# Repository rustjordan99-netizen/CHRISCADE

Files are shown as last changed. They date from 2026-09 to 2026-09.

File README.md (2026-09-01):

# CHRISCADE

**A custom RP2040 handheld console with a 3D-printed shell, touch-first UI,
Game Boy / Game Boy Color emulation, microSD storage, and a small app library.**

## Quick start

Ready-to-flash firmware is in the clearly marked
[FLASH-ME](FLASH-ME/) folder. Open it and use
[`CHRISCADE_v273_FLASH_THIS.uf2`](FLASH-ME/CHRISCADE_v273_FLASH_THIS.uf2).
The [3MF-FILES](3MF-FILES/) folder contains the printable enclosure parts.
The author-supplied optimized Crystal test build is documented in
[OPTIMIZED-CRYSTAL](OPTIMIZED-CRYSTAL/).

<p align="center">
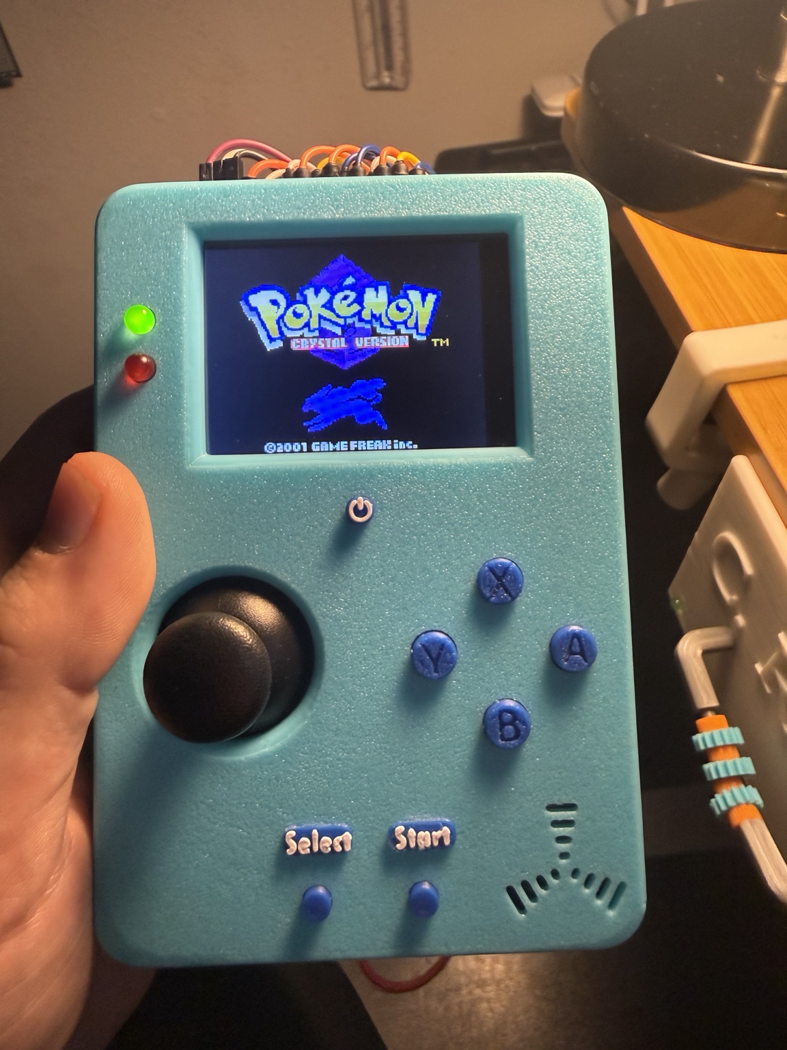
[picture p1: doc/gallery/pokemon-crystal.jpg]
CHRISCADE running Pokémon Crystal
  
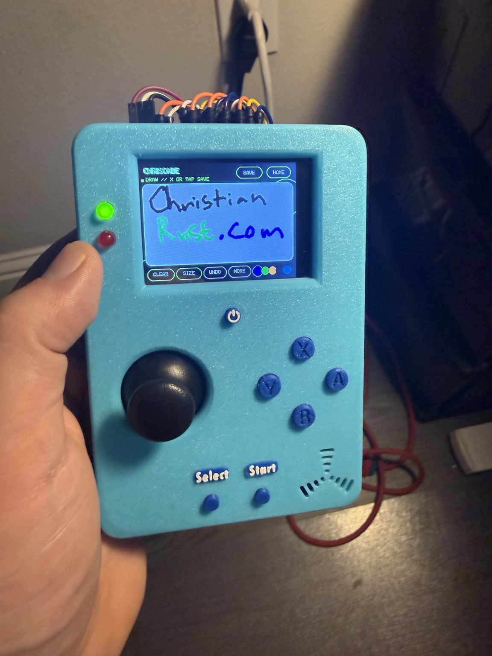
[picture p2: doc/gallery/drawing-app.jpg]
CHRISCADE drawing app
  
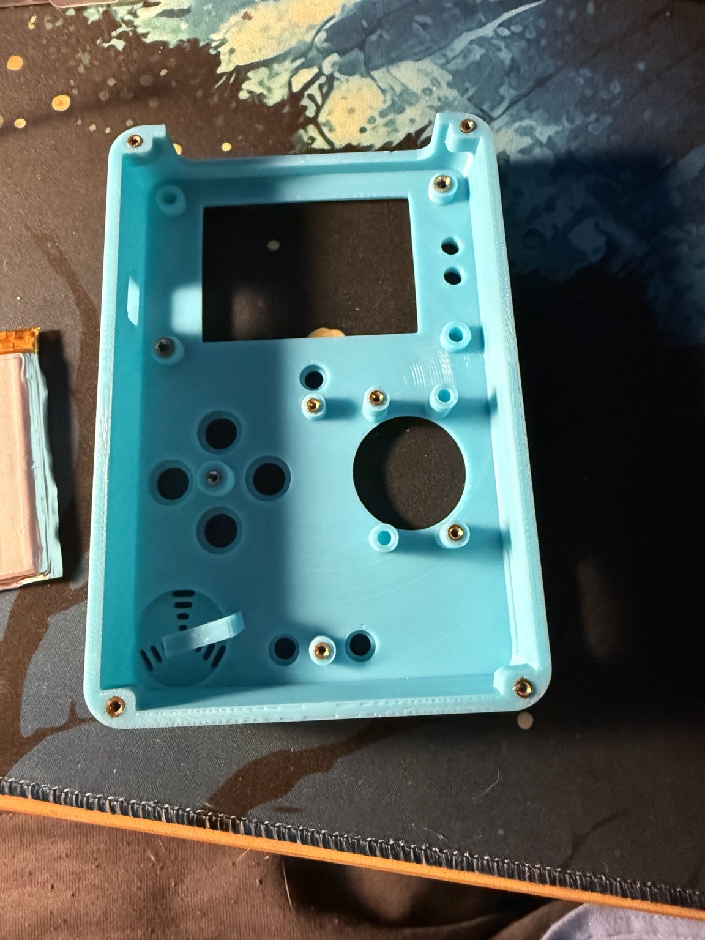
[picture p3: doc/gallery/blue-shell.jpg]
CHRISCADE printed shell interior
  
</p>

<p align="center"><i>From enclosure concept to printed handheld and custom firmware.</i></p>

<p align="center">
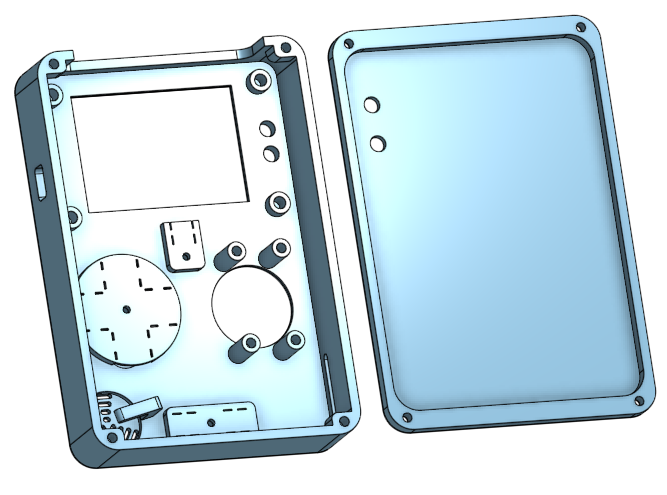
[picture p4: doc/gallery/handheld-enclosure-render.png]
CHRISCADE enclosure CAD render
  
</p>

## What it does

- Runs legally owned Game Boy and Game Boy Color games from a FAT32 microSD card
- Saves game progress to the SD card
- Includes an author-supplied optimized Pokémon Crystal test-build workflow for this RP2040 handheld
- Provides a themed game launcher with touch and physical controls
- Includes Draw, Calculator, Timer / Stopwatch / Alarm, Metronome, Settings, and Gallery apps
- Captures screenshots into per-game and per-app SD folders; screenshots can be renamed or edited
- Supports a custom animated boot sequence, boot themes/sounds, brightness, LEDs, battery status, audio, and sleep controls
- Uses a USB game-transfer workflow so games can be managed without removing the SD card

## Hardware

- CrowPanel RP2040 touchscreen controller/display
- Parallax joystick
- 6 mm A/B/X/Y buttons and approximately 3.3 mm Start, Select, and Power buttons
- 10 kΩ volume potentiometer, speaker/amplifier, status LEDs, microSD, and jumper wiring
- Custom 3D-printed enclosure and controls

The printable shell and button files, component list, and assembly notes are in
[hardware/README.md](hardware/README.md).
The printable files are also directly accessible in the root
[3MF-FILES](3MF-FILES/) folder.

## CHRISCADE pinout

This is the active CrowPanel RP2040 configuration in `platformio.ini` and
`src/common.h`:

| Function | Pico GPIO / mapping |
| --- | --- |
| A / B buttons | GP0 / GP1 |
| X / Y buttons | GP2 / GP3 |
| Start / Select | GP4 / GP5 |
| Low-power button | GP20 |
| Joystick X / Y | GP26 / GP27 (analog) |
| Speaker audio | GP19 (PWM) |
| Volume potentiometer | GP28 (analog) |
| TFT SCLK / MOSI / MISO | GP10 / GP11 / GP12 |
| TFT CS / DC / RST / backlight | GP9 / GP8 / GP15 / GP18 |
| Touch controller CS | GP16 |
| microSD CS | GP22 |

The TFT, touch controller, and microSD share the SPI1 bus on GP10–GP12 and
use separate chip-select lines. The six directional controls are handled by
the CrowPanel input mapping in firmware; the joystick supplies the analog
direction input. Verify the board revision and wiring before connecting power.

## Build

Install PlatformIO, then build the `pico` environment:

```sh
pio run -e pico
```

The UF2 is created at `.pio/build/pico/firmware.uf2`. Hold BOOTSEL while
connecting the Pico, then copy that file to the mounted `RPI-RP2` drive.

## Limitations

- Game Boy / Game Boy Color compatibility is experimental; some games may
  freeze, fail to launch, or run below full speed.
- The optimized Pokémon Crystal build is a hardware-specific test build, not a
  general replacement for every Crystal ROM or emulator.
- Larger or more demanding GBC games can still stutter, especially during
  overworld streaming, audio-heavy scenes, or menu transitions.
- The RP2040 is overclocked for emulation performance. This can increase heat,
  power use, and long-term hardware stress.
- The current build reserves part of the Pico's flash for the firmware and
  filesystem, so usable ROM capacity is lower than the board's advertised
  flash size.
- SPI display bandwidth and shared peripherals can limit frame rate and may
  produce occasional tearing or input/audio artifacts.
- The enclosure and wiring are custom hardware; fit, button feel, battery
  behavior, and pin compatibility depend on the individual build.
- Only use game files you legally own. ROMs, saves, screenshots, and generated
  firmware binaries are not included in the source repository.

> This repository includes firmware, CAD, and documentation only. It does not
> contain commercial ROMs, save data, screenshots, or generated UF2 releases.
> The optimized Crystal build was provided by Chris Rust for testing, but the
> game file itself is not redistributed here. Use only game dumps you legally own.

## Credits

CHRISCADE is a heavily customized fork built on
[YouMakeTech's Pico-GB](https://github.com/YouMakeTech/Pico-GB), itself based
on deltabeard's Peanut-GB / RP2040-GB work. Thanks to those projects and their
contributors, as well as Bodmer's TFT_eSPI and the other libraries included in
this source tree. Their license notices remain with their respective code.

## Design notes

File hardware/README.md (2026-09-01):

# CHRISCADE hardware

## Core components

| Part | Used in this build |
| --- | --- |
| Main controller/display | CrowPanel RP2040 with integrated touch display |
| Analog control | Parallax joystick |
| Main buttons | 6 mm diameter buttons for A, B, X, and Y |
| Small buttons | Approximately 3.3 mm buttons for Start, Select, and Power |
| Volume | 10 kΩ potentiometer and printed volume spinner |
| Wiring | Jumper wires; quantity and lengths depend on enclosure routing |
| Enclosure | Custom 3D-printed shell and control parts |

The firmware pin assignments and electrical behavior are defined in the source
configuration. Check them before changing any component or wiring.

## Printable files

All printable parts are in the easy-to-find root-level [`3MF-FILES/`](../3MF-FILES/)
folder:

| File | Part |
| --- | --- |
| `front shell.3mf` | Front half of the handheld shell |
| `back.3mf` | Rear half of the handheld shell |
| `button panel.3mf` | Button-panel insert |
| `ABXY.3mf` | A/B/X/Y button set |
| `small buttons.3mf` | Small auxiliary button set |
| `select.3mf` | Select button |
| `start stop.3mf` | Start/Stop button |
| `power.3mf` | Power button |
| `volume spinner.3mf` | Knob for the 10 kΩ volume potentiometer |

## Assembly notes

- Test the display, controls, SD card, speaker, and power wiring before closing
  the case.
- Keep jumper wiring clear of the joystick and button travel.
- Test-fit buttons and the volume knob after printing; printer tolerances vary.
- The CAD files are supplied as `.3mf`, which can be opened directly in most
  modern slicers.

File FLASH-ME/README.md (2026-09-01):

# Flash CHRISCADE

## Use this file

Copy [`CHRISCADE_v273_FLASH_THIS.uf2`](CHRISCADE_v273_FLASH_THIS.uf2) to the
CrowPanel RP2040:

1. Disconnect USB power from the handheld.
2. Hold the board's **BOOTSEL** button while connecting the USB cable.
3. Release BOOTSEL when the `RPI-RP2` drive appears.
4. Copy `CHRISCADE_v273_FLASH_THIS.uf2` onto the `RPI-RP2` drive.
5. Wait for the drive to disappear and the handheld to reboot.

This is the tested v273 build. It includes the gallery folder cleanup, exact
Game Library folder logos, no-flash Undo repaint, and multi-stroke Undo.

Flashing firmware does not erase game saves stored on the microSD card. Keep
the card inserted during normal use, but do not confuse the `RPI-RP2` drive
with the game microSD card.

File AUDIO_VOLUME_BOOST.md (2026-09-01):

# Shared gameplay volume boost — 2026-08-30

New firmware: `CROWPANEL_PICO_GB_ALL_GAMES_LOUDER_AUDIO.uf2`

SHA256: `66492CBF863AC2E16DC949E77C91C271DD29683BA592F66CAFC0C889C4D8CEA5`

Built on the fine-tuned audio firmware. The boost is in the common
`crowpanel_audio_submit` output path, so every GB/GBC game, including GBZ files,
uses it. There are no title checks or per-ROM patches. Doom firmware and the
startup/UI sounds are not changed.

The startup jingle can use full-amplitude square-wave tones. Gameplay audio
mixes several channels, averages stereo to mono, filters the result, and limits
peaks; these have different average loudness. Both already use the same 700/4000
volume-knob thresholds and cubic taper.

The new `audio_output_curve.h` adds 1.5x gain before the existing soft limiter,
precomputed into the existing 321-byte table. Quiet/moderate signals are boosted
more than already-loud peaks. This is not a guarantee of 50% greater perceived
loudness or an exact jingle loudness match. The soft limiter reduces hard
clipping but cannot guarantee distortion-free physical speaker output.

No per-sample arithmetic or table RAM is added. Sample rate, 266 MHz clock,
filter, volume/mute controls, audio queue/IRQ refinements, rendering, saves,
settings and sleep behavior are retained.

Verification:

- Production curve compiled for Cortex-M0+ and executed under Unicorn: all
  321 entries passed silence, monotonicity, non-attenuation, soft-knee continuity,
  signed PWM symmetry and range tests. All larger uint16 inputs clamp safely.
- Queue startup/refill/recovery/reset and 50,000 randomized interleavings passed.
- Release Pico build passed: RAM 257,804 / 262,144 (unchanged), flash
  324,928 / 782,336. Existing unrelated build warnings remain.
- UF2 block numbering, magic and RP2040 family checked: 1,319 blocks, highest
  payload end 0x10052700, below ROM storage at 0x100BF000.
- Previous fine-tune, click-fix, DMA-queue and stable UF2 hashes rechecked;
  none overwritten. No ROM/save/settings files changed. Not auto-flashed.

Hardware test: begin below maximum volume, compare the same scenes with the
previous fine-tune build at the same knob position, and listen for harshness in
busy music/effects. Test more than one game, full mute/resume, and map scrolling.
Actual loudness and speaker distortion still require this listening test.

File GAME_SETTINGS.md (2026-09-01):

# Game-library file settings — 2026-08-30

Firmware: `CROWPANEL_PICO_GB_GAME_SETTINGS.uf2`

SHA256: `3B1583F108E37D3654220772001CB49984AE92162B9525EAADD059A8E6AF7128`

Built on the all-games louder-audio firmware; retains that boost, the guarded
audio queue, sound-generation optimizations and existing game/display settings.

## Controls

- Highlight a game in Game Library and press SELECT, or tap the bottom-right
  SELECT SETTINGS button. B still returns Home; A still loads a game.
- Settings offers Rename and Delete for that highlighted SD file. Touch works,
  as do Up/Down and A. B/SELECT, or tapping the settings footer, returns.
- Rename uses a touch keyboard with uppercase/lowercase, digits, punctuation,
  Space, Delete-character, Clear, Save and Back. The stick and A also operate
  the keyboard; START saves and B cancels. The original extension is kept.
- Delete opens a separate confirmation showing the complete filename, with
  Cancel selected by default. Choose Right then A, or tap Delete, to confirm.
  B/SELECT cancels. Entry input must be released before a new action is read,
  so holding the opening A press/touch cannot also confirm deletion.
- After rename, the A-Z list follows the renamed file to its new position.
  After deletion, selection is clamped and an empty final page returns to the
  previous page. An entirely empty library still supports Back and Settings.

## File protection and limitations

- Only the exact selected `.gb`, `.gbc` or `.gbz` root-directory file is targeted.
  No recursion, paths, wildcard deletion or filesystem formatting.
- The filename policy rejects path separators, control/invalid FAT characters,
  empty/oversized names and Windows device names. Rename preserves extension.
- Existing destination files/directories are never overwritten. SdFat's own
  exclusive-create rename behavior also enforces this. Case-only renames are
  reported as unchanged because the SD filesystem is case-insensitive.
- Read-only files and directories are not modified. Missing files and I/O
  failures are reported rather than treated as successful operations.
- Save filenames are derived from the internal ROM header, not the SD filename.
  These menus never rename or delete save/settings files.
- Deletion removes the SD ROM file. There is no on-device trash/undo; restore
  it by copying the original ROM back. The last flashed ROM on the Pico is not
  erased, so START Last Game can still run that cached copy.
- Avoid removing power/card during any SD update. As with existing save writes,
  filesystem/power failures cannot be made fully transactional here.

## Implementation and verification

- UI uses the current theme helpers, rounded controls and existing click sound.
  Focus and keyboard edits redraw only their changed controls/field.
- The rename editor reuses 512 bytes of the existing flash-sector workspace
  while in menus; it allocates no new persistent buffer or gameplay work.
- `src/rom_file_actions.h` contains the shared filename rules and exact file
  operation. `tests/run_rom_file_actions_test.py` compiles this production code
  for Cortex-M0+ and executes it with an in-memory fake filesystem under Unicorn.
- Tests passed for bounded names, extension retention, UTF-8 filenames,
  traversal/invalid names, case-insensitive collisions, directories, read-only
  attributes, absent files, simulated I/O failures, single-file rename/delete
  and preservation of other game/save/settings entries. No real game file was
  opened, renamed or deleted by these tests.
- Confirm/cancel input release handling, keyboard bounds and page refresh paths
  were source-reviewed. Physical touchscreen behavior still needs a board test.
- Final release build passed. Static RAM **257,804 / 262,144 bytes** (unchanged);
  flash **341,448 / 782,336 bytes**. Menu buffers stay off the small core-0 stack.
- UF2 checked: **1,384 RP2040 blocks**, payload ends **0x10056800**, before ROM
  storage at **0x100BF000**. ROM capacity is unchanged.
- All five prior stable/audio firmware hashes were checked and remain intact.
  New UF2 is separate and has not been flashed automatically.

On-device check: cancel a delete first (A on default Cancel, B, and touch), then
try renaming a test ROM, a duplicate-name rejection, and deleting a backed-up
test ROM. Check the last entry on a page, the empty library, and loading its
existing save after a rename. No actual SD-card files were changed during this
development task.

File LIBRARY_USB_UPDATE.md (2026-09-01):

# CHRISCADE library update — 2026-08-30

Firmware: `CROWPANEL_PICO_GB_LIBRARY_USB_UPDATE.uf2`

SHA256: `E043BF24B14F014035DF7B46D6E470A0CF10B83B0BD06601FF5B4DA20D14B3DC`

## Library and editing

- Removed left/right page controls. Up/Down continuously scrolls through the
  alphabetical library, revealing one game at a time at the visible edge.
  Selection stops at the beginning/end rather than wrapping. Only eight names
  are held in memory; scrolling doesn't allocate the whole library.
- After the final game, Down highlights ADD GAME; Up returns to the last game.
  ADD GAME is also always available by touching its bottom-left button, including
  in an empty library. A opens the highlighted game or Add Game. B returns Home.
- Bottom-right button reads `SELECT // SETTINGS`. It and the physical Select
  button open Rename/Delete for the highlighted game. Existing delete-confirmation
  and save-preservation behavior remains intact.
- Rename has a visible insertion cursor. Tap the name to place it, use the
  on-screen arrows, or press X/Y to move left/right. Typing inserts at that point;
  DEL removes the previous character, not the entire suffix. The view follows
  the cursor for long names, and the original extension is kept.
- The small game-list and larger cartridge-writing Pokeballs share a circular
  pixel mask. Red fill and white fill cannot extend beyond the black outline.

## Add a game without removing the SD card

1. Flash this UF2 as usual, then open Game Library > ADD GAME.
2. Connect the handheld to the PC using a USB data cable.
3. Double-click `SEND_GAME_USB.cmd` in this project folder.
4. Choose a `.gb`, `.gbc`, or `.gbz` file. Select the handheld's COM port from
   the list (not an unrelated serial device).
5. Wait for the verified-success message, then press B on the handheld. The
   refreshed library includes the new file in alphabetical order.

This uses USB serial, **not a drive in File Explorer**. The Windows launcher
uses the existing Python runtime and project-local pyserial, without installing
anything new. Advanced usage: `send_game_usb.py --port COM5 "path/to/Game.gb"`.
Close any serial monitor holding the same COM port before running it.

The uploader accepts only new ROM files at the SD root. It cannot read files
back, expose raw sectors, overwrite existing names, format the card, or delete
other files. Saves/settings are not upload targets. Pick a different filename
if a game already exists. The 16 MiB transfer cap is not a new emulator/flash
capacity: existing ROM-size and supported-format limits still apply when loading.

Uploads use bounded 512-byte acknowledged chunks and a streaming CRC32 check.
The ROM appears in the library only after successful verification and rename
from an exclusively created temporary file. B cancels; a stalled transfer times
out after ten seconds without a byte. Cancellation/error attempts to remove only
that session's new temporary file. Existing temporary files are never reused or
removed. Sudden power loss or card failure can leave an incomplete `CC*.TMP`
file; it is not shown as a game. As with all SD writes, avoid unplugging power or
removing the card during the transfer—filesystem corruption cannot be ruled out.
Deep-sleep polling pauses during an active transfer and resumes afterward.

## Implementation and checks

- USB reception and SD writes run in the menu foreground, before the second
  display core and emulator audio start. No USB callback touches the shared SPI
  bus. Raw USB mass storage remains disabled.
- Reuses the existing flash-sector workspace for upload data, rename text and
  directory-scan scratch at nonoverlapping offsets. No new persistent buffer or
  per-frame gameplay work. Nested filename buffers were moved off core 0's 2 KB
  stack. Only changed rows/controls repaint while scrolling, not the full screen.
- Release build passes: static RAM **257,804 / 262,144 bytes**, unchanged;
  flash **352,696 / 782,336 bytes**.
- UF2 verified: **1,428 RP2040 blocks**, payload end **0x10059400**, safely below
  the ROM area at **0x100BF000**. All six previous stable/recent firmware hashes
  remain unchanged. No board was flashed automatically.
- `tests/run_library_update_tests.py`: actual Cortex-M0+ helper code, fake SD.
  Covers cursor insertion/deletion/UTF-8/bounds, both Pokeball masks, continuous
  scrolling for libraries of 0–30 games, short shifted windows after deletion,
  upload header/CRC validation, exclusive creation, existing-name collisions,
  write/sync/rename failures, cancellation, and preservation of original files.
  Includes the earlier rename/delete policy regression tests.
- `tests/test_usb_rom_sender.py`: five tests, mock serial/in-memory files only;
  exact payloads across chunk boundaries, Unicode filenames, duplicates,
  incomplete writes, rejected extensions and empty inputs.
- Audio regressions pass: 50,000 queue interleavings; 4,096 sample/state-exact APU
  frames against the stored reference; all 321 output-table entries and bounds.
  Existing all-games loudness boost and 266 MHz clock setting are unchanged.

Physical touchscreen, USB throughput and actual SD transfer still need a board
test. Start with a backed-up ROM under a new test filename, then try a duplicate
upload (must be refused) and B cancellation. No real game/save files were changed
by development tests.

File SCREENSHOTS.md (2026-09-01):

# In-game screenshots

Press X once during gameplay to save the displayed game frame. The game pauses
briefly during SD access and resumes automatically. A two-click shutter confirms
a successful save; a low double beep means capture failed (for example, a full
gallery or SD error). Both respect the physical volume pot, including mute.

Open App Library > Screenshots to view/delete pictures. The existing four shared
drawing/screenshot slots and RGB565 file format are unchanged. Game captures are
labelled with the ROM's internal title. Existing pictures and saves are preserved.
If the four slots are occupied, delete an unwanted picture before capturing.

Implementation: capture the completed 160x144 indexed RAM frame and current
palette. Reconstruct native/stretch/aspect scaling into the existing 320-pixel
DMA scratch row and publish the 320x240 image through the same verified temporary
file/rename path as drawings. Core 1 drains DMA and yields the SPI bus cooperatively;
it is not reset, and TFT DMA is not reinitialized. No TFT GRAM readback is used.
Gameplay audio's existing DMA channel and PCM scratch buffer provide feedback;
the boot-tone driver is not invoked while gameplay owns the speaker.

Tests: run `tests/run_drawing_test.py` with the project's ARM/Unicorn dependencies.
It compares every exported pixel for GB and GBC in all scaling modes, exercises
the shared save-failure/collision paths, checks the shutter envelope, and retains
the drawing regression tests. Physical-device SPI handoff and sound still require
on-device testing (repeat captures, mute, full gallery and resume in GB/GBC).

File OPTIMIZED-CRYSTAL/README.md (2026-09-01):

# Optimized Pokémon Crystal build

The optimized Pokémon Crystal test build used with CHRISCADE was provided by
the project author, Chris Rust, for performance testing on this handheld. It
is kept separate from the firmware and CAD repository because game files are
not redistributed here.

To use your legally owned copy, place the compatible optimized build on the
microSD card alongside your other game files. CHRISCADE supports the compressed
`.gbz` workflow used by the optimized Crystal build as well as standard `.gb`
and `.gbc` files, depending on the firmware build.

The optimized build is intended for the CHRISCADE RP2040 configuration and may
not work correctly in other emulators or on other hardware.

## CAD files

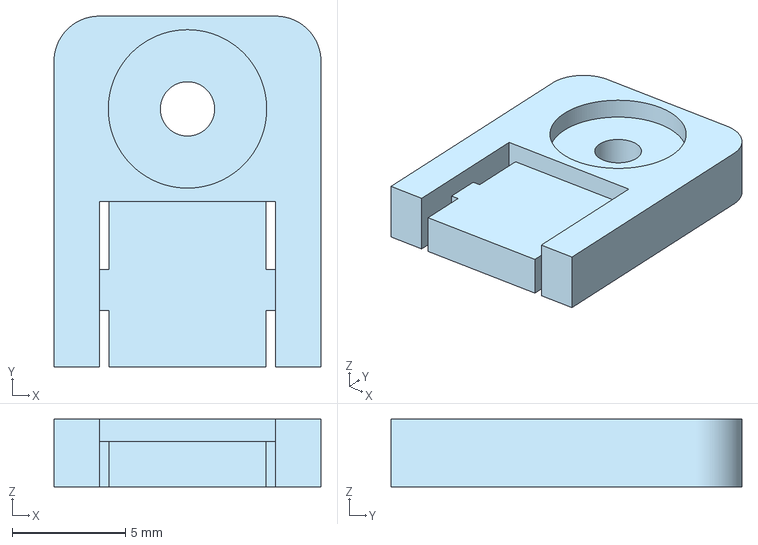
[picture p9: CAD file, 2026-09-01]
3MF-FILES/power.3mf
11.8 x 15.5 x 3.00 mm

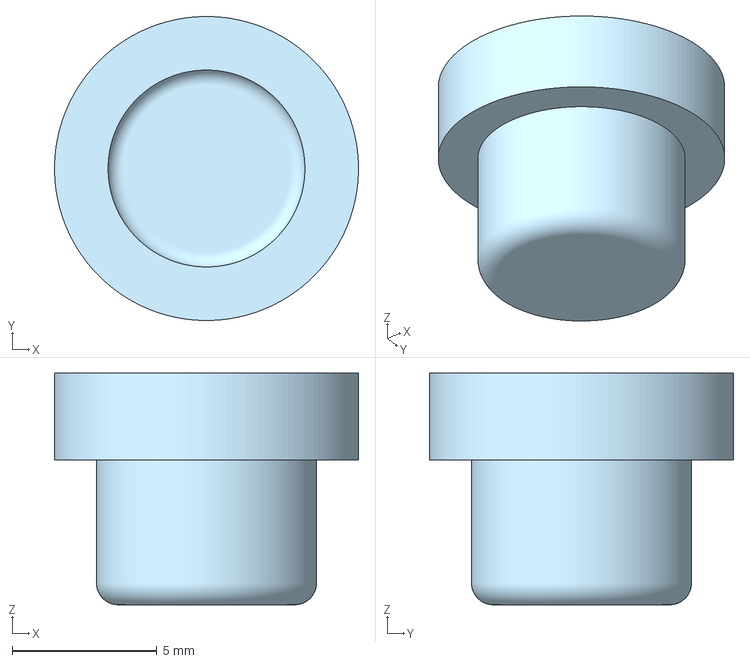
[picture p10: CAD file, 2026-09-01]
3MF-FILES/ABXY.3mf
10.5 x 10.5 x 8.00 mm

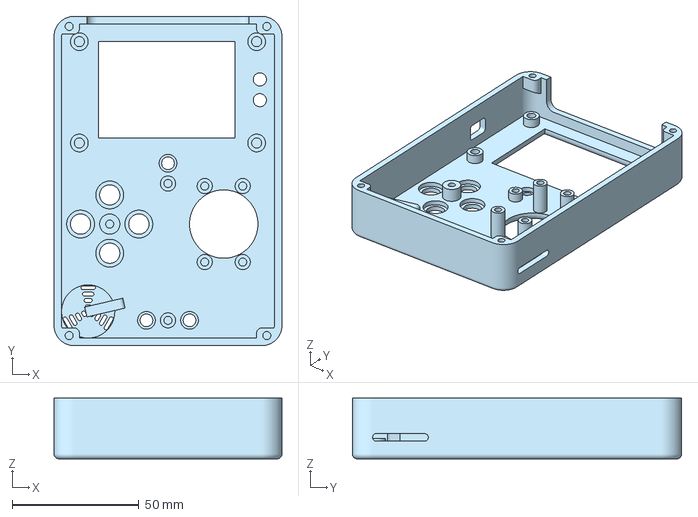
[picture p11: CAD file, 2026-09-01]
3MF-FILES/front shell.3mf
90.0 x 130.0 x 24.0 mm

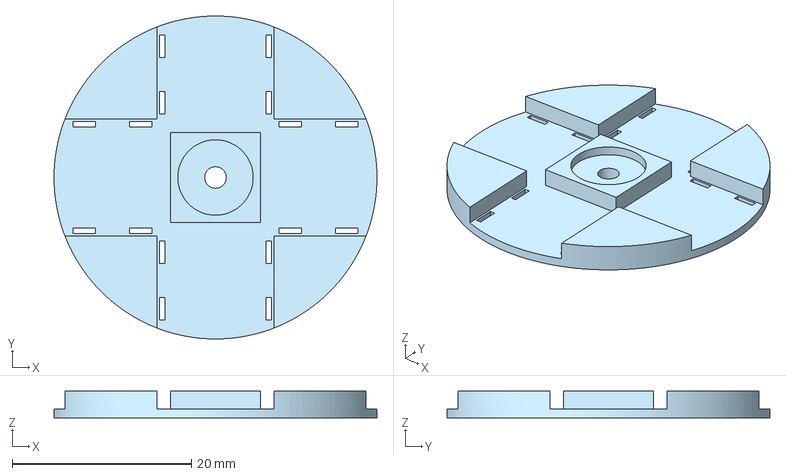
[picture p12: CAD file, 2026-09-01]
3MF-FILES/button panel.3mf
36.0 x 36.0 x 3.00 mm

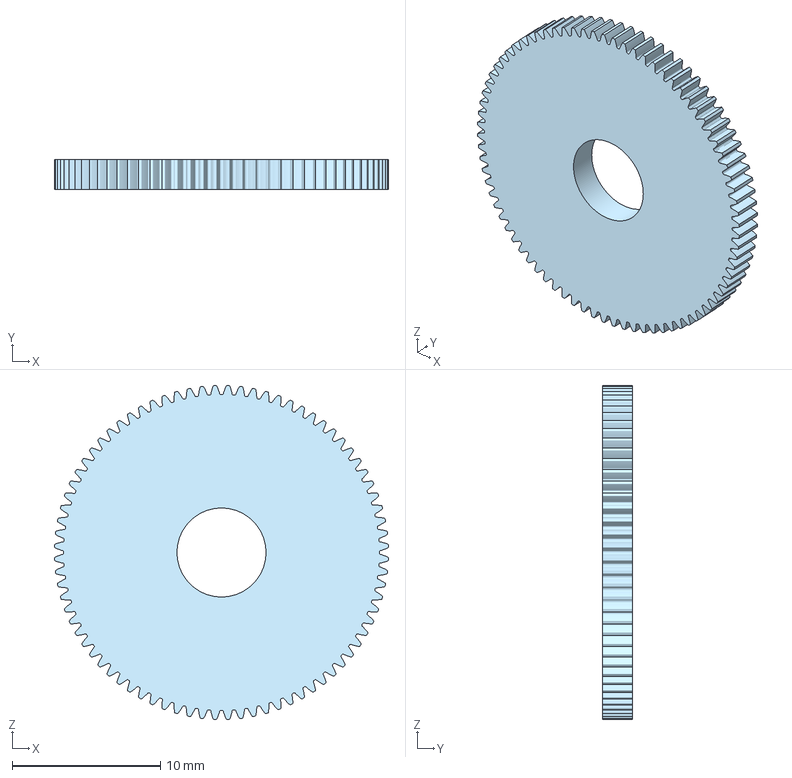
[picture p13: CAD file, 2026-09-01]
3MF-FILES/volume spinner.3mf
22.5 x 2.00 x 22.5 mm

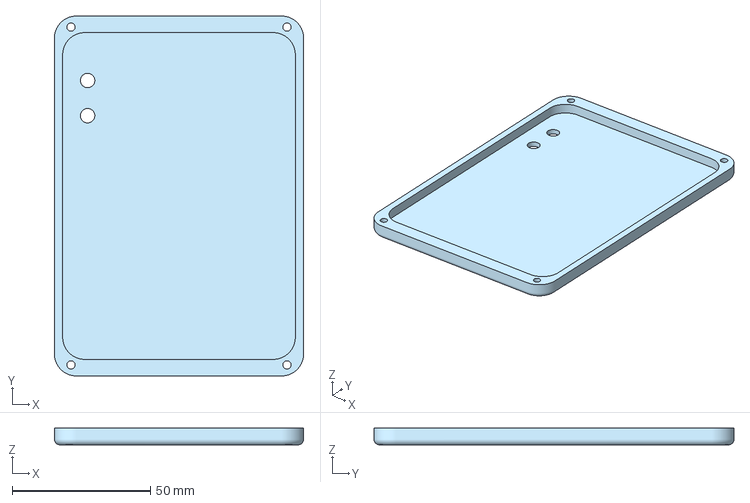
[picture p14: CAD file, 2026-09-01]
3MF-FILES/back.3mf
90.0 x 130.0 x 6.00 mm

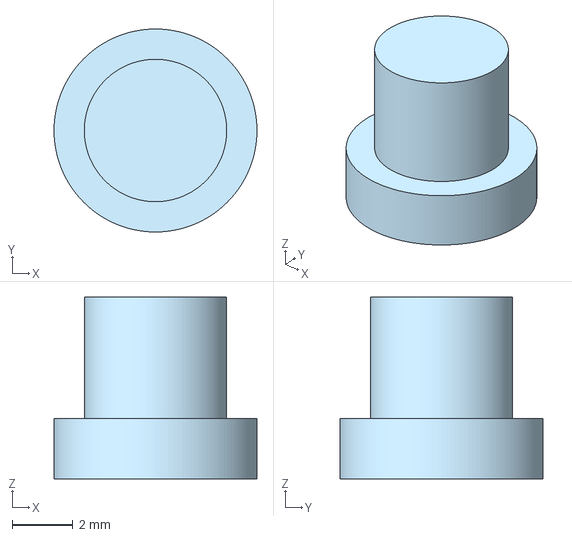
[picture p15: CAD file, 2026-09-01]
3MF-FILES/small buttons.3mf
6.70 x 6.70 x 6.00 mm

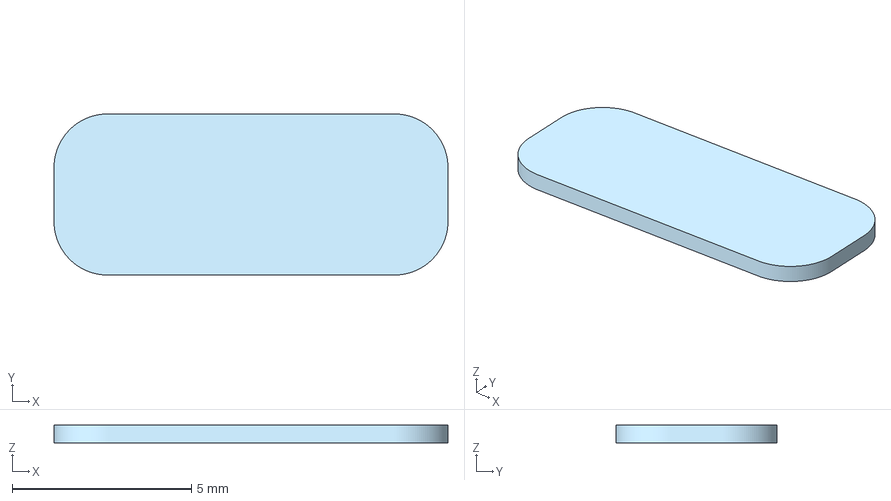
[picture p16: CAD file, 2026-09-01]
3MF-FILES/select.3mf
11.0 x 4.50 x 0.5 mm

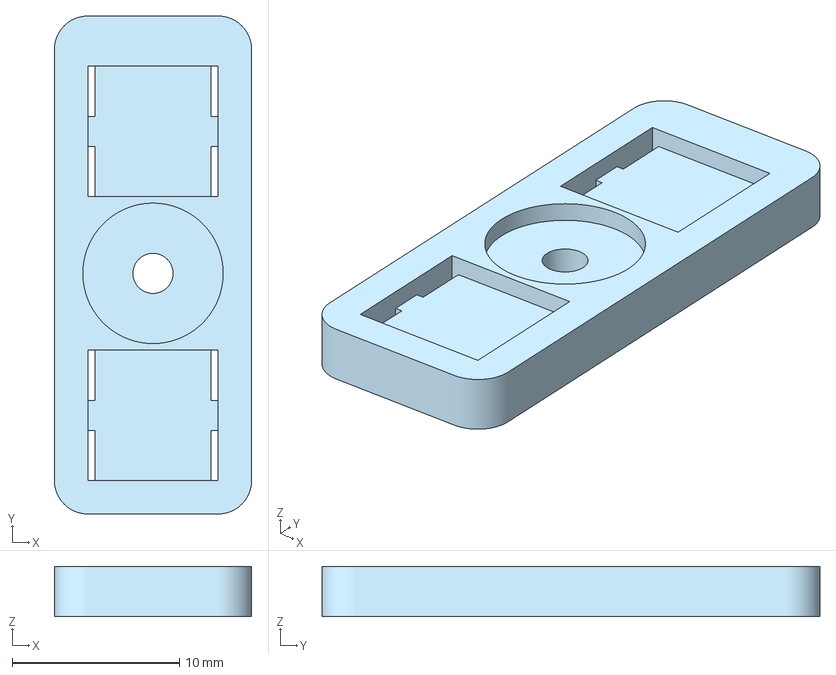
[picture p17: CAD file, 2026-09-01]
3MF-FILES/start stop.3mf
11.8 x 29.8 x 3.00 mm

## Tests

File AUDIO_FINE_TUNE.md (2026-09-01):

# Audio fine-tune — 2026-08-30

## Starting point and retained gains

The user reported that queued DMA eliminated walking slowdown, and the guarded
three-buffer queue reduced the subsequent click to almost negligible. This
build starts from `CROWPANEL_PICO_GB_CRYSTAL_AUDIO_CLICK_FIX.uf2`, not an older
slow build.

Retained without retuning or removing:

- CGB first-ten-sprites-per-scanline culling and simplified sprite priority.
- Fast eight-pixel background segments and nibble expansion, hidden-background
  skipping behind the window, cached scanline register inputs.
- Precomputed display scaling, four-pixel row hashing, palette-change checks,
  and conversion only for changed rows.
- Display DMA line storage in scratch X SRAM, independent of main RAM traffic.
- Display dispatch after audio submission, two stable source framebuffers,
  and suppression of rendering when the display cannot accept a frame.
- Existing direct CPU memory accesses, wide accesses, cached ROM pointers and
  WRAM-to-VRAM DMA copies. These are retained, not claimed as independently
  proven gains from this pass.
- Three explicitly owned audio blocks, high-priority DMA transfers, safe
  address reset on every block, no unsafe automatic chain/replay, and the
  existing short startup/underrun blend.
- Ten-bit PWM, soft-limiter/level lookup tables, 22,050 Hz sample rate, existing
  filter and volume curve, and muted-game speed limiting.

The neutral whole-frame sprite-list cache remains removed to leave space for
the third audio buffer. No higher overclock or additional framebuffer/cache
allocation is introduced. CPU remains at the existing 266 MHz setting, with
its existing fallback. Screen size, ROM storage, saves, UI, settings, touch,
LEDs and sleep behavior are not edited.

## New refinements

1. Remove provably zero integer contributions in square, wave and noise
   phase-transition loops. The old code divided the phase fraction BEFORE
   multiplying by sample amplitude, so it always truncated to zero. Every
   oscillator, sweep, envelope and length transition is preserved.
2. Read only the final wave-table phase for each output sample, and replace
   wave output division with exact signed power-of-two scaling. Negative
   samples still truncate toward zero. Hoist stable stereo routing gains out
   of the per-sample loops for all channels.
3. Replace queue cursor modulo-three operations with increment-and-wrap
   branches, reducing completion-path overhead without changing ownership.
4. Temporarily raise DMA_IRQ_1 CPU priority to 0x40 if it was lower priority.
   This lets the short SRAM completion handler preempt default-priority work
   near the ~45 us sample deadline. Preserve any already-higher priority and
   restore the original value on audio shutdown. DMA transfer priority was
   already high and remains so.

These changes provide extra audio-production headroom and a faster block
handoff; they do not establish that the remaining physical click is eliminated.

## Verification

- Release `pico` build passed. Existing APU MAX/MIN macro redefinition warnings
  remain; they predate this change.
- Static RAM: **257,804 / 262,144 bytes**, 604 fewer than the starting build.
  Runtime heap headroom remains tight; no new allocation was added.
- Flash: **324,936 / 782,336 bytes**, 496 fewer than the starting build.
- Linked audio callback and completion handler are in SRAM. The display DMA
  line buffer remains at 0x20040000 in scratch X.
- `tests/run_apu_differential_test.py` compiles both the untouched local APU
  reference and current production source for Cortex-M0+, then runs them with
  Unicorn. **512 scenarios / 4,096 audio frames** matched every stereo sample,
  register read, and internal state byte. Covers channel frequency extremes,
  counter boundaries, duty cycles, wave volume, routing, envelopes, sweeps,
  retriggers, muted/disabled channels, power changes and randomized writes.
- A synthetic four-channel callback used **121,663 vs 213,598 guest ARM
  instructions (43.0% fewer)**. This measures only that synthetic callback,
  not whole-game speed or real MCU cycles, bus contention or IRQ timing.
- Production queue tests passed startup, delayed conversion, underrun recovery,
  reset and **50,000 randomized producer/consumer interleavings**.
- Tests are outside the firmware build. `tests/apu_reference.cpp` is a frozen
  copy of the pre-change local source, with its original license header.
- UF2: 1,319 valid RP2040 blocks, payload ends at **0x10052700**, before ROM
  storage at **0x100BF000**. No SD/ROM/save/settings files were modified.

Run both test scripts with the project-local `.audio-test-tools` on PYTHONPATH
using the bundled Python runtime. They require the existing ARM toolchain.

## Firmware

New file: `CROWPANEL_PICO_GB_CRYSTAL_AUDIO_FINE_TUNE.uf2`

SHA256: `D1D55345DB4DC5EFC2FDCACC946E4805B656822D538285876990B177940D9D75`

Previous binaries preserved and hashes rechecked:

- `CROWPANEL_PICO_GB_CRYSTAL_AUDIO_CLICK_FIX.uf2`:
  `431EE532D3AE9EEEC208BB39CD84BF891AD22DB46A2F72063D59A0A85B92DB0E`
- `CROWPANEL_PICO_GB_CRYSTAL_AUDIO_DMA_QUEUE.uf2`:
  `9D23C894665C6DA02E0126D31C0A35E6D4B604C886F9F10C00D231A37E32EBC9`
- `CROWPANEL_PICO_GB_SD_SAVE.uf2`:
  `502C6868A5D238A8C2760B4B4589B9D2F23BB1177DC89292A2B799230575CBA6`

Not automatically flashed. On the handheld compare walking into new map areas
against standing still, bumping into a wall and opening the menu. Also check
volume mute/resume, sleep/wake, and another game such as Mario for regressions.

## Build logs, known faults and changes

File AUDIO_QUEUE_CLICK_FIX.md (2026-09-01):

# Scrolling audio click fix

The user confirmed `CROWPANEL_PICO_GB_CRYSTAL_AUDIO_DMA_QUEUE.uf2` eliminated
the lag, but introduced clicks while walking. Keep that binary for comparison.

## Confirmed code defect (audible result still needs hardware testing)

The old two-channel chain treated an idle DMA channel as a free buffer.
On RP2040, a chain trigger reloads the original transfer count but does not
rewind READ_ADDR. A delayed producer can therefore cause an automatic restart
past the end of the old buffer. The old "both channels idle" recovery does not
reliably detect this condition. See the SDK's RP2040 `DMA_CH0_TRANS_COUNT`
register description or RP2040 datasheet section 2.5.1.1.

## Changes

- Three blocks with explicit FREE/FILLING/READY/PLAYING ownership.
- One non-chaining DMA channel; its shared DMA_IRQ_1 completion handler starts
  only a completed READY block and resets its source address every time.
- Conversion cannot overwrite a queued or playing block. Completion during
  conversion cannot consume a partially filled block.
- High DMA scheduling priority for the small audio transfers.
- Eight-sample boundary blend only at startup or after an actual underrun.
  Normal audio blocks, volume/gain, sample rate and CPU clock are unchanged.
- Mute and shutdown mask this channel's IRQ, abort, acknowledge stale completion
  and reset ownership. They do not disable the shared IRQ line for other users.
- Removed the 1,584-byte whole-frame sprite-list cache (reported neutral in
  testing) to fund the third audio block. The first-ten-sprites-per-line
  optimization and other renderer/CPU/display optimizations are retained.

## Verification

- Pico release build succeeded: static RAM 258,408 / 262,144 bytes;
  flash 325,432 / 782,336 bytes. Runtime heap headroom remains tight.
- `tests/run_audio_queue_test.py` compiles the production queue for Cortex-M0+
  and executes it under Unicorn. Startup, invalid publishes, full queues,
  completion during refill, underruns, resets and 50,000 randomized interleavings
  passed. This tests queue logic, not actual IRQ latency or physical audio.
- Test-only Unicorn package is project-local in `.audio-test-tools`.
  Set PYTHONPATH to that directory and run the test runner with bundled Python.
- Protected stable firmware SHA256:
  `502C6868A5D238A8C2760B4B4589B9D2F23BB1177DC89292A2B799230575CBA6`.
- Original lag-free queued-audio firmware SHA256:
  `9D23C894665C6DA02E0126D31C0A35E6D4B604C886F9F10C00D231A37E32EBC9`.

The new build is not flashed automatically. Test scrolling, menu music, volume
mute/resume and sleep/wake on the board. No ROM, save or settings files changed.

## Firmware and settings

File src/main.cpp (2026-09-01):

/**
 * Copyright (C) 2022 by Mahyar Koshkouei <mk@deltabeard.com>
 *
 * Permission to use, copy, modify, and/or distribute this software for any
 * purpose with or without fee is hereby granted.
 *
 * THE SOFTWARE IS PROVIDED "AS IS" AND THE AUTHOR DISCLAIMS ALL WARRANTIES WITH
 * REGARD TO THIS SOFTWARE INCLUDING ALL IMPLIED WARRANTIES OF MERCHANTABILITY
 * AND FITNESS. IN NO EVENT SHALL THE AUTHOR BE LIABLE FOR ANY SPECIAL, DIRECT,
 * INDIRECT, OR CONSEQUENTIAL DAMAGES OR ANY DAMAGES WHATSOEVER RESULTING FROM
 * LOSS OF USE, DATA OR PROFITS, WHETHER IN AN ACTION OF CONTRACT, NEGLIGENCE OR
 * OTHER TORTIOUS ACTION, ARISING OUT OF OR IN CONNECTION WITH THE USE OR
 * PERFORMANCE OF THIS SOFTWARE.
 */

#include "gb.h"

// C Headers
#include <stdio.h>
#include <stdlib.h>
#include <string.h>

// Project headers
#include "hedley.h"

#include "common.h"
#include "input.h"
#include "chriscade_boot.h"
#include "chriscade_settings.h"

#include <hardware/clocks.h>
#include <hardware/vreg.h>
#include <pico/time.h>

#if ENABLE_SDCARD
#include "card_loader.h"
#include "SdFat.h"
#ifdef ENABLE_USB_STORAGE_DEVICE
#include "msc.h"
#endif
#endif

#if ENABLE_SOUND
#if defined(CROWPANEL_PWM_AUDIO)
#include "crowpanel_audio.h"
#else
#include "i2s-audio.h"
#endif
#include "minigb_apu.h"

/**
 * Global variables for audio task
 * stream contains N=AUDIO_SAMPLES samples
 * each sample is 32 bits
 * 16 bits for the left channel + 16 bits for the right channel in stereo interleaved format)
 * This is intended to be played at AUDIO_SAMPLE_RATE Hz
 */
uint16_t* stream;

#if !defined(CROWPANEL_PWM_AUDIO)
i2s_config_t i2s_config;
#endif
#endif

uint_fast32_t frames = 0;

#if ENABLE_SOUND && defined(CROWPANEL_PWM_AUDIO)
static constexpr uint64_t GAMEBOY_FRAME_US = 16743;
static uint64_t muted_frame_deadline_us;
static bool muted_frame_pacing_active;

static void pace_muted_frame(bool muted, uint64_t frame_started_us) {
  if (!muted) {
    muted_frame_pacing_active = false;
    return;
  }

  uint64_t now = time_us_64();
  if (!muted_frame_pacing_active ||
      now > muted_frame_deadline_us + GAMEBOY_FRAME_US * 2u) {
    muted_frame_deadline_us = frame_started_us + GAMEBOY_FRAME_US;
    muted_frame_pacing_active = true;
  } else {
    muted_frame_deadline_us += GAMEBOY_FRAME_US;
  }

  if (now < muted_frame_deadline_us)
    busy_wait_until(from_us_since_boot(muted_frame_deadline_us));
}
#endif

void initSound();

void startEmulator() {
#if ENABLE_LCD
#if ENABLE_SDCARD
  Serial.println("Starting ROM file selector ...");
  rom_file_selector();
#endif
#endif

  sleep_ms(100);

  Serial.println("Init GB context ...");  
  initGbContext();

  /* Automatically assign a colour palette to the game */
  char rom_title[17];
  auto_assign_palette(palette, gb_colour_hash(&gb), gb_get_rom_name(&gb, rom_title));

#if ENABLE_SDCARD
  // The LCD and SD card share SPI1 on CrowPanel. Finish all SD access before
  // core 1 reinitializes and takes ownership of the display bus.
  Serial.println("Load save file ...");
  read_cart_ram_file(&gb);
#endif

#if defined(CROWPANEL_ILI9341)
  // 300 MHz was unstable on this board, so retain the proven 266 MHz clock.
  vreg_set_voltage(VREG_VOLTAGE_1_25);
  sleep_ms(10);
  const bool clock_set = set_sys_clock_khz(266000u, false);
  if (!clock_set) {
    vreg_set_voltage(VREG_VOLTAGE_1_20);
    sleep_ms(10);
    set_sys_clock_khz(240000, true);
  }
#endif

  initSound();

#if ENABLE_LCD
  gb_init_lcd(&gb, &lcd_draw_line);

  /* Start Core1, which processes requests to the LCD. */
  Serial.println("Starting Core1 ...");
  multicore_launch_core1(core1_init);
#endif

#if ENABLE_SOUND
  // Initialize audio emulation
  Serial.println("Starting audio ...");
  audio_init();
#endif

  Serial.print("\n> ");
}

void reset(uint32_t sleepMs) {
  Serial.println("\nEmulation Ended");

  sleep_ms(sleepMs);

  /* stop lcd task running on core 1 */
  multicore_reset_core1();
  watchdog_reboot(0, 0, 0);
}

void halt() {
  while (true) {}
}

void initSound() {
#if ENABLE_SOUND
  Serial.println("Initialize Sound ...");

  // Allocate memory for the stream buffer
  stream = (uint16_t*) malloc(AUDIO_BUFFER_SIZE_BYTES);
  assert(stream != NULL);
  memset(stream, 0, AUDIO_BUFFER_SIZE_BYTES); // Zero out the stream buffer

#if defined(CROWPANEL_PWM_AUDIO)
  crowpanel_audio_init();
#else
  // Initialize I2S sound driver
  i2s_config = i2s_get_default_config();
  i2s_config.sample_freq = AUDIO_SAMPLE_RATE;
  i2s_config.dma_trans_count = AUDIO_SAMPLES;
  i2s_config.data_pin = I2S_DIN_PIN,
	i2s_config.clock_pin_base = I2S_BCLK_LRC_PIN_BASE,
  i2s_volume(&i2s_config, 2);
  i2s_init(&i2s_config);
#endif

  Serial.println("Sound initialized");
#endif
}

void setup() {
#if defined(CROWPANEL_ILI9341)
  // Keep every other device on the shared SPI1 bus deselected during startup.
  gpio_init(TOUCH_CS_PIN);
  gpio_set_dir(TOUCH_CS_PIN, true);
  gpio_put(TOUCH_CS_PIN, true);
  gpio_init(SD_CS_PIN);
  gpio_set_dir(SD_CS_PIN, true);
  gpio_put(SD_CS_PIN, true);
#endif
#if ENABLE_LCD
  lcd_init(false);
#endif

  // Initialise USB serial connection for debugging.
  Serial.begin(115200);
  //while (!Serial) ;
  //delay(2000);

  chriscade_power_init();
#if ENABLE_SDCARD
  // Settings live beside ROMs and saves, so mount the card before rendering
  // the configurable startup sequence.
  init_sdcard();
  chriscade_settings_load();
  chriscade_status_led_apply();
#endif
#if ENABLE_LCD
  chriscade_brightness_init();
  chriscade_boot_screen();
#endif

#if ENABLE_SDCARD
#if ENABLE_USB_STORAGE_DEVICE
  initUsbStorageDevice();
#endif
#endif
  
  initJoypad();

  startEmulator();
}

void loop() {
#if ENABLE_SOUND && defined(CROWPANEL_PWM_AUDIO)
  const uint64_t frame_started_us = time_us_64();
#endif
  // Run the hot frame scheduler and CPU stepper together from SRAM so each
  // emulated instruction avoids crossing the flash-to-RAM veneer.
  runGbFrameFast();

  frames++;
#if ENABLE_SOUND
#if defined(CROWPANEL_PWM_AUDIO)
  // Fully skip APU mixing and PWM/DMA conversion at the physical minimum
  // volume setting. This trades muted-audio accuracy for more game CPU time.
  const bool audio_muted = crowpanel_audio_performance_muted();
  if (!audio_muted) {
    audio_callback(NULL, (int16_t*) stream, AUDIO_BUFFER_SIZE_BYTES);
    crowpanel_audio_submit((int16_t*) stream, AUDIO_BUFFER_SIZE_BYTES);
  }
  // Audio DMA normally supplies native-speed pacing.  Preserve that pacing
  // when the pot is at minimum so mute improves headroom without turbo-charging
  // Mario or other games.
  pace_muted_frame(audio_muted, frame_started_us);
#else
  audio_callback(NULL, (int16_t*) stream, AUDIO_BUFFER_SIZE_BYTES);
  i2s_dma_write(&i2s_config, (int16_t*) stream);
#endif
#endif

#if ENABLE_LCD
  // Start the next screen transfer only after the new PWM block is playing.
  // Scrolling can then consume shared SRAM/display bandwidth without delaying
  // preparation of the audio block that must cover that transfer.
  lcd_present_pending_frame();
#endif

  handleJoypad();
  chriscade_power_poll(true);
  handleSerial();
}

void error(String message) {
  tft.fillScreen(TFT_BLACK);
  tft.setTextColor(TFT_RED);
  tft.drawString(message, 0, ERROR_TEXT_OFFSET, FONT_ID);
  Serial.printf("E %s\n", message.c_str());
  Serial.flush();
  reset(5000);
}

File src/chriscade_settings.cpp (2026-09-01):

#include <Arduino.h>

#include "card_loader.h"
#include "chriscade_apps.h"
#include "chriscade_backlight.pio.h"
#include "chriscade_boot.h"
#include "chriscade_settings.h"
#include ".generated/chriscade_build_version.h"
#include "touch_control_settings.h"
#include "common.h"
#include "input.h"

#include <hardware/clocks.h>
#include <hardware/adc.h>
#include <hardware/flash.h>
#include <hardware/gpio.h>
#include <hardware/pio.h>
#include <hardware/pio_instructions.h>
#include <pico/bootrom.h>

static constexpr uint32_t SETTINGS_MAGIC = 0x43485354u; // "CHST"
static constexpr uint8_t SETTINGS_VERSION = 5;
static constexpr char SETTINGS_FILE[] = "CHRIS.CFG";
static constexpr uint BACKLIGHT_PIN = 18;
static constexpr uint STATUS_LED_POWER_PIN = 6;
static constexpr uint32_t BACKLIGHT_PERIOD = 255;

struct ChriscadeSettingsFile {
  uint32_t magic;
  uint32_t checksum;
  uint8_t version;
  uint8_t brightness_index;
  uint8_t status_led_enabled;
  uint8_t boot_sound;
  uint8_t boot_theme;
  uint8_t random_boot;
  uint8_t quick_boot;
  uint8_t touch_controls; // v5 bit flags; v4 gameplay boolean in the same byte
};
static_assert(sizeof(ChriscadeSettingsFile) == 16, "Keep saved settings compatible");

static ChriscadeSettingsFile settings;
static uint8_t runtime_boot_sound;
static uint8_t runtime_boot_theme;
static PIO backlight_pio = pio1;
static int backlight_sm = -1;
static uint backlight_program_offset;

static uint32_t settings_checksum(const ChriscadeSettingsFile& value) {
  const uint8_t* bytes = reinterpret_cast<const uint8_t*>(&value.version);
  uint32_t hash = 2166136261u;
  for (size_t i = 0; i < sizeof(value) - offsetof(ChriscadeSettingsFile, version); ++i) {
    hash ^= bytes[i];
    hash *= 16777619u;
  }
  return hash;
}

static void settings_defaults() {
  memset(&settings, 0, sizeof(settings));
  settings.magic = SETTINGS_MAGIC;
  settings.version = SETTINGS_VERSION;
  settings.brightness_index = 4;
  settings.status_led_enabled = 1;
  settings.touch_controls = TouchControlSettings::DEFAULTS;
  settings.quick_boot = 0;
  settings.boot_sound = (uint8_t)ChriscadeBootSound::ARCADE;
  settings.boot_theme = (uint8_t)ChriscadeBootTheme::NEON;
  settings.random_boot = 0;
  runtime_boot_sound = settings.boot_sound;
  runtime_boot_theme = settings.boot_theme;
  settings.checksum = settings_checksum(settings);
}

static bool settings_valid(const ChriscadeSettingsFile& value) {
  return value.magic == SETTINGS_MAGIC &&
      (value.version >= 1 && value.version <= SETTINGS_VERSION) &&
      value.brightness_index < 5 && value.status_led_enabled < 2 &&
      value.boot_sound <= (uint8_t)ChriscadeBootSound::VICTORY &&
      value.boot_theme <= (uint8_t)ChriscadeBootTheme::ROYAL &&
      value.random_boot < 2 &&
      value.quick_boot < 2 &&
      TouchControlSettings::valid(value.version, value.touch_controls) &&
      value.checksum == settings_checksum(value);
}

static bool settings_save() {
  settings.magic = SETTINGS_MAGIC;
  settings.version = SETTINGS_VERSION;
  settings.checksum = settings_checksum(settings);
  FsFile file;
  auto scope = UseSDPinFunctionScope();
  if (!file.open(SETTINGS_FILE, O_WRONLY | O_CREAT | O_TRUNC)) return false;
  bool success = file.write(&settings, sizeof(settings)) == sizeof(settings);
  file.sync();
  file.close();
  return success;
}

void chriscade_settings_load() {
  settings_defaults();
  ChriscadeSettingsFile loaded = {};
  bool migrated = false;
  FsFile file;
  {
    auto scope = UseSDPinFunctionScope();
    if (file.open(SETTINGS_FILE, O_RDONLY)) {
      if (file.read(&loaded, sizeof(loaded)) == sizeof(loaded) && settings_valid(loaded)) {
        settings = loaded;
        if (settings.version == 1) {
          // Version 1 stored Quick Boot in the byte now used by Status LED.
          // Preserve that choice while defaulting the new green LED option on.
          settings.quick_boot = settings.status_led_enabled;
          settings.status_led_enabled = 1;
        } else if (settings.version == 2) {
          // Version 2 had the LED option but temporarily removed Quick Boot.
          settings.quick_boot = 0;
        }
        settings.touch_controls = TouchControlSettings::migrate(
            loaded.version, loaded.touch_controls);
        migrated = loaded.version != SETTINGS_VERSION;
        settings.version = SETTINGS_VERSION;
      }
      file.close();
    }
  }
  if (migrated) settings_save();
  runtime_boot_sound = settings.boot_sound;
  runtime_boot_theme = settings.boot_theme;
  if (settings.random_boot) {
    // ADC noise and the variable SD-mount time provide a fresh non-security
    // seed. Random boot always chooses an audible sound, never OFF.
    randomSeed(time_us_32() ^ ((uint32_t)adc_read() << 16));
    runtime_boot_sound = (uint8_t)random(1, 7);
    runtime_boot_theme = (uint8_t)random(0, 5);
  }
}
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

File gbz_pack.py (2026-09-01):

#!/usr/bin/env python3
"""Pack a legally obtained GB/GBC ROM into CHRISCADE's banked GBZ format."""

from __future__ import annotations

import argparse
import pathlib
import struct
import sys
import zlib


MAGIC = 0x315A4247  # GBZ1
VERSION = 1
HEADER_SIZE = 4096
BANK_SIZE = 16384
MAX_BANKS = 128
FLAG_DEFLATE = 1
FLAG_LZ4 = 2
HEADER_FORMAT = "<IHHIHHIIII"
ENTRY_FORMAT = "<IHHI"


def _lz4_length(output: bytearray, length: int) -> None:
    while length >= 255:
        output.append(255)
        length -= 255
    output.append(length)


def lz4_compress(block: bytes) -> bytes:
    """Create a raw LZ4 block using a small deterministic hash-table encoder."""
    output = bytearray()
    table: list[list[int]] = [[] for _ in range(16384)]
    anchor = 0
    position = 0
    limit = len(block) - 4

    def hash_at(offset: int) -> int:
        sequence = int.from_bytes(block[offset : offset + 4], "little")
        return ((sequence * 2654435761) & 0xFFFFFFFF) >> 18

    def remember(offset: int) -> None:
        bucket = table[hash_at(offset)]
        bucket.append(offset)
        if len(bucket) > 8:
            del bucket[0]

    while position <= limit:
        hash_value = hash_at(position)
        best_reference = -1
        best_match_end = position
        for reference in reversed(table[hash_value]):
            if block[reference : reference + 4] != block[position : position + 4]:
                continue
            candidate_end = position + 4
            reference_end = reference + 4
            while (
                candidate_end < len(block)
                and block[candidate_end] == block[reference_end]
            ):
                candidate_end += 1
                reference_end += 1
            if candidate_end > best_match_end:
                best_reference = reference
                best_match_end = candidate_end

        remember(position)
        if best_reference < 0:
            position += 1
            continue

        literal_length = position - anchor
        match_length = best_match_end - position - 4
        output.append((min(literal_length, 15) << 4) | min(match_length, 15))
        if literal_length >= 15:
            _lz4_length(output, literal_length - 15)
        output.extend(block[anchor:position])
        output.extend(struct.pack("<H", position - best_reference))
        if match_length >= 15:
            _lz4_length(output, match_length - 15)

        for update in range(position + 1, best_match_end):
            if update <= limit:
                remember(update)
        position = best_match_end
        anchor = best_match_end

    literal_length = len(block) - anchor
    output.append(min(literal_length, 15) << 4)
    if literal_length >= 15:
        _lz4_length(output, literal_length - 15)
    output.extend(block[anchor:])
    return bytes(output)


def lz4_decompress(block: bytes) -> bytes:
    output = bytearray()
    position = 0
    while position < len(block):
        token = block[position]
        position += 1
        literal_length = token >> 4
        if literal_length == 15:
            while True:
                extension = block[position]
                position += 1
                literal_length += extension
                if extension != 255:
                    break
        output.extend(block[position : position + literal_length])
        position += literal_length
        if position == len(block):
            break
        offset = struct.unpack_from("<H", block, position)[0]
        position += 2
        match_length = (token & 15) + 4
        if (token & 15) == 15:
            while True:
                extension = block[position]
                position += 1
                match_length += extension
                if extension != 255:
                    break
        for _ in range(match_length):
            output.append(output[-offset])
    return bytes(output)


def parse_bank_list(specification: str) -> set[int]:
    banks: set[int] = set()
    if not specification:
        return banks
    for item in specification.split(","):
        item = item.strip()
        if not item:
            continue
        if "-" in item:
            first_text, last_text = item.split("-", 1)
            first = int(first_text, 0)
            last = int(last_text, 0)
            if last < first:
                raise ValueError(f"invalid descending bank range: {item}")
            banks.update(range(first, last + 1))
        else:
            banks.add(int(item, 0))
    return banks


def pack_rom(
    source: pathlib.Path,
    destination: pathlib.Path,
    raw_banks: set[int],
    codec: str,
) -> None:
    rom = source.read_bytes()
    if not rom or len(rom) % BANK_SIZE:
        raise ValueError("ROM size must be a non-zero multiple of 16 KB")
    bank_count = len(rom) // BANK_SIZE
    if bank_count > MAX_BANKS:
        raise ValueError(f"ROM has {bank_count} banks; GBZ supports at most {MAX_BANKS}")
    invalid_banks = sorted(bank for bank in raw_banks if bank < 0 or bank >= bank_count)
    if invalid_banks:
        raise ValueError(f"raw bank outside ROM: {invalid_banks[0]}")

    payload = bytearray()
    entries: list[tuple[int, int, int, int]] = []
    for bank_number in range(bank_count):
        bank = rom[bank_number * BANK_SIZE : (bank_number + 1) * BANK_SIZE]
        compressor = zlib.compressobj(level=9, wbits=-15)
        deflated = compressor.compress(bank) + compressor.flush()
        lz4 = lz4_compress(bank) if codec in ("lz4", "auto") else b""
        if lz4 and lz4_decompress(lz4) != bank:
            raise ValueError(f"internal LZ4 verification failed for bank {bank_number}")
        if codec == "deflate":
            compressed, compressed_flag = deflated, FLAG_DEFLATE
        elif codec == "lz4":
            compressed, compressed_flag = lz4, FLAG_LZ4
        else:
            compressed, compressed_flag = min(
                ((deflated, FLAG_DEFLATE), (lz4, FLAG_LZ4)), key=lambda item: len(item[0])
            )
        if bank_number not in raw_banks and len(compressed) < len(bank):
            stored = compressed
            flags = compressed_flag
        else:
            stored = bank
            flags = 0
        offset = HEADER_SIZE + len(payload)
        entries.append((offset, len(stored), flags, zlib.crc32(bank) & 0xFFFFFFFF))
        payload.extend(stored)

    total_size = HEADER_SIZE + len(payload)
    if total_size > 1280 * 1024:
        raise ValueError(
            f"Compressed container is {total_size:,} bytes and exceeds the 1.25 MiB slot"
        )
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

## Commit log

2026-09-01 Initial CHRISCADE firmware, hardware, and documentation
    [ABXY.3mf, back.3mf, button panel.3mf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]
2026-09-01 Showcase CHRISCADE build and CAD gallery
2026-09-01 Add easy access 3MF print files folder
    [ABXY.3mf, back.3mf, button panel.3mf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]
